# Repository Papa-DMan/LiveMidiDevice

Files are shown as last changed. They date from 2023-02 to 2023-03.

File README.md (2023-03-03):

# LiveMidiDevice
This repo merges my personal MIDI-Controller-DisplayDriver and MIDI-Controller repositories into this public one and also hosts the schematics and pcb designs for the project

The MIDI-Controller uses a tree and node structure. A FRDMK64F Dev board is the root of the tree and can handle up to two nodes right now. It utilizes the I2C bus with an extender chipset from TI to send data and power over an RJ45 8 connector cable down to the nodes that contain up to 8 buttons and 1 expression pedal and 1 led display controlled by and stm32 l412kb dev board.

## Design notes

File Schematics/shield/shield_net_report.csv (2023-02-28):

Net Code | Net Name | Pad Count | Via Count | Via Length | Track Length | Die Length | Net Length
001 | GND | 7 | 0 | 0.0000 mm | 80.9573 mm | 0.0000 mm | 80.9573 mm
002 | A0 | 3 | 0 | 0.0000 mm | 24.4699 mm | 0.0000 mm | 24.4699 mm
003 | A1 | 3 | 0 | 0.0000 mm | 15.3445 mm | 0.0000 mm | 15.3445 mm
004 | A4 | 3 | 0 | 0.0000 mm | 12.0241 mm | 0.0000 mm | 12.0241 mm
005 | A5 | 3 | 0 | 0.0000 mm | 17.7821 mm | 0.0000 mm | 17.7821 mm
006 | 5V | 15 | 0 | 0.0000 mm | 109.7009 mm | 0.0000 mm | 109.7009 mm
013 | VIN | 1 | 0 | 0.0000 mm | 0.0000 mm | 0.0000 mm | 0.0000 mm
014 | RST | 1 | 0 | 0.0000 mm | 0.0000 mm | 0.0000 mm | 0.0000 mm
015 | P3V3 | 1 | 0 | 0.0000 mm | 0.0000 mm | 0.0000 mm | 0.0000 mm
016 | Net-(U2-Pad5) | 4 | 0 | 0.0000 mm | 22.8535 mm | 0.0000 mm | 22.8535 mm
017 | Net-(U2-Pad2) | 4 | 0 | 0.0000 mm | 31.0575 mm | 0.0000 mm | 31.0575 mm
018 | Net-(U1-Pad5) | 4 | 0 | 0.0000 mm | 23.1029 mm | 0.0000 mm | 23.1029 mm
019 | Net-(U1-Pad2) | 4 | 0 | 0.0000 mm | 29.7947 mm | 0.0000 mm | 29.7947 mm
020 | D9 | 1 | 0 | 0.0000 mm | 0.0000 mm | 0.0000 mm | 0.0000 mm
021 | D8 | 1 | 0 | 0.0000 mm | 0.0000 mm | 0.0000 mm | 0.0000 mm
022 | D7B | 1 | 0 | 0.0000 mm | 0.0000 mm | 0.0000 mm | 0.0000 mm
023 | D7 | 2 | 0 | 0.0000 mm | 25.2753 mm | 0.0000 mm | 25.2753 mm
024 | D6B | 1 | 0 | 0.0000 mm | 0.0000 mm | 0.0000 mm | 0.0000 mm
025 | D6 | 2 | 0 | 0.0000 mm | 27.5409 mm | 0.0000 mm | 27.5409 mm
026 | D5B | 1 | 0 | 0.0000 mm | 0.0000 mm | 0.0000 mm | 0.0000 mm
027 | D5 | 1 | 0 | 0.0000 mm | 0.0000 mm | 0.0000 mm | 0.0000 mm
028 | D4B | 1 | 0 | 0.0000 mm | 0.0000 mm | 0.0000 mm | 0.0000 mm
029 | D4 | 1 | 0 | 0.0000 mm | 0.0000 mm | 0.0000 mm | 0.0000 mm
030 | D3B | 1 | 0 | 0.0000 mm | 0.0000 mm | 0.0000 mm | 0.0000 mm
031 | D3 | 1 | 0 | 0.0000 mm | 0.0000 mm | 0.0000 mm | 0.0000 mm
032 | D2B | 1 | 0 | 0.0000 mm | 0.0000 mm | 0.0000 mm | 0.0000 mm
033 | D2 | 1 | 0 | 0.0000 mm | 0.0000 mm | 0.0000 mm | 0.0000 mm
034 | D1B | 1 | 0 | 0.0000 mm | 0.0000 mm | 0.0000 mm | 0.0000 mm
035 | D15 | 1 | 0 | 0.0000 mm | 0.0000 mm | 0.0000 mm | 0.0000 mm
036 | D14 | 1 | 0 | 0.0000 mm | 0.0000 mm | 0.0000 mm | 0.0000 mm
037 | D13 | 1 | 0 | 0.0000 mm | 0.0000 mm | 0.0000 mm | 0.0000 mm
038 | D12 | 1 | 0 | 0.0000 mm | 0.0000 mm | 0.0000 mm | 0.0000 mm
039 | D11 | 1 | 0 | 0.0000 mm | 0.0000 mm | 0.0000 mm | 0.0000 mm
040 | D10 | 1 | 0 | 0.0000 mm | 0.0000 mm | 0.0000 mm | 0.0000 mm
041 | D1 | 1 | 0 | 0.0000 mm | 0.0000 mm | 0.0000 mm | 0.0000 mm
042 | D0B | 1 | 0 | 0.0000 mm | 0.0000 mm | 0.0000 mm | 0.0000 mm
043 | D0 | 1 | 0 | 0.0000 mm | 0.0000 mm | 0.0000 mm | 0.0000 mm
044 | AREF | 1 | 0 | 0.0000 mm | 0.0000 mm | 0.0000 mm | 0.0000 mm
045 | AD9 | 1 | 0 | 0.0000 mm | 0.0000 mm | 0.0000 mm | 0.0000 mm
046 | AD8 | 1 | 0 | 0.0000 mm | 0.0000 mm | 0.0000 mm | 0.0000 mm
047 | AD17 | 1 | 0 | 0.0000 mm | 0.0000 mm | 0.0000 mm | 0.0000 mm
048 | AD16 | 1 | 0 | 0.0000 mm | 0.0000 mm | 0.0000 mm | 0.0000 mm
049 | AD14 | 1 | 0 | 0.0000 mm | 0.0000 mm | 0.0000 mm | 0.0000 mm
050 | AD13 | 1 | 0 | 0.0000 mm | 0.0000 mm | 0.0000 mm | 0.0000 mm
051 | AD12 | 1 | 0 | 0.0000 mm | 0.0000 mm | 0.0000 mm | 0.0000 mm
052 | AD11 | 1 | 0 | 0.0000 mm | 0.0000 mm | 0.0000 mm | 0.0000 mm
053 | AD10 | 1 | 0 | 0.0000 mm | 0.0000 mm | 0.0000 mm | 0.0000 mm
054 | A9B | 1 | 0 | 0.0000 mm | 0.0000 mm | 0.0000 mm | 0.0000 mm
055 | A8B | 1 | 0 | 0.0000 mm | 0.0000 mm | 0.0000 mm | 0.0000 mm
056 | A7B | 1 | 0 | 0.0000 mm | 0.0000 mm | 0.0000 mm | 0.0000 mm
057 | A6B | 1 | 0 | 0.0000 mm | 0.0000 mm | 0.0000 mm | 0.0000 mm
058 | A5B | 1 | 0 | 0.0000 mm | 0.0000 mm | 0.0000 mm | 0.0000 mm
059 | A4B | 1 | 0 | 0.0000 mm | 0.0000 mm | 0.0000 mm | 0.0000 mm
060 | A3B | 1 | 0 | 0.0000 mm | 0.0000 mm | 0.0000 mm | 0.0000 mm
061 | A3 | 1 | 0 | 0.0000 mm | 0.0000 mm | 0.0000 mm | 0.0000 mm
062 | A2B | 1 | 0 | 0.0000 mm | 0.0000 mm | 0.0000 mm | 0.0000 mm
063 | A2 | 1 | 0 | 0.0000 mm | 0.0000 mm | 0.0000 mm | 0.0000 mm
064 | A1B | 1 | 0 | 0.0000 mm | 0.0000 mm | 0.0000 mm | 0.0000 mm
065 | A13B | 1 | 0 | 0.0000 mm | 0.0000 mm | 0.0000 mm | 0.0000 mm
066 | A12B | 1 | 0 | 0.0000 mm | 0.0000 mm | 0.0000 mm | 0.0000 mm
067 | A11B | 1 | 0 | 0.0000 mm | 0.0000 mm | 0.0000 mm | 0.0000 mm
068 | A10B | 1 | 0 | 0.0000 mm | 0.0000 mm | 0.0000 mm | 0.0000 mm
069 | A0B | 1 | 0 | 0.0000 mm | 0.0000 mm | 0.0000 mm | 0.0000 mm

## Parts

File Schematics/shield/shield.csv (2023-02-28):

Id | Designator | Package | Quantity | Designation | Supplier and ref
1 | R20,R18,R19,R17 | R_Axial_DIN0414_L11.9mm_D4.5mm_P5.08mm_Vertical | 4 | 91
2 | R9,R12,R11,R10 | R_Axial_DIN0207_L6.3mm_D2.5mm_P2.54mm_Vertical | 4 | 100k
3 | R25 | R_Axial_DIN0207_L6.3mm_D2.5mm_P2.54mm_Vertical | 1 | 5k1
4 | R24,R23,R22,R21 | R_1206_3216Metric_Pad1.30x1.75mm_HandSolder | 4 | 634
5 | R16,R15,R14,R13 | R_Axial_DIN0207_L6.3mm_D2.5mm_P2.54mm_Vertical | 4 | 10k
6 | R8,R7,R6,R5 | R_Axial_DIN0207_L6.3mm_D2.5mm_P2.54mm_Vertical | 4 | 5K1
7 | R4,R3,R2,R1 | R_Axial_DIN0207_L6.3mm_D2.5mm_P2.54mm_Vertical | 4 | 330
8 | U2,U1 | DIP-8_W7.62mm | 2 | P82B96
9 | C5,C6,C4,C3 | CP_Radial_Tantal_D5.5mm_P5.00mm | 4 | 10 uF
10 | U4,U3 | Texas_S-PVSON-N10 | 2 | OPA1622
11 | C18,C16,C19,C14,C21 | C_0402_1005Metric_Pad0.74x0.62mm_HandSolder | 5 | 0.01uF
12 | C8,C10,C7,C9 | C_1812_4532Metric_Pad1.57x3.40mm_HandSolder | 4 | COG 470pF
13 | U5 | SOIC-24 | 1 | CS5381K
14 | J2,J1 | RJ45_Amphenol_RJHSE538X | 2 | RJ45
15 | J4 | PinHeader_2x06_P2.54mm_Vertical | 1 | J4
16 | C1,C2 | C_Disc_D3.0mm_W1.6mm_P2.50mm | 2 | C
17 | C13 | C_1210_3225Metric_Pad1.33x2.70mm_HandSolder | 1 | 220uF
18 | C15,C17,C20 | C_0603_1608Metric_Pad1.08x0.95mm_HandSolder | 3 | 1uF
19 | J5 | PinHeader_2x10_P2.54mm_Vertical | 1 | J2
20 | J6 | PinHeader_2x08_P2.54mm_Vertical | 1 | J1
21 | C11,C12 | CP_Radial_D5.0mm_P2.50mm | 2 | 2700pF
22 | J3 | PinHeader_2x08_P2.54mm_Vertical | 1 | J3

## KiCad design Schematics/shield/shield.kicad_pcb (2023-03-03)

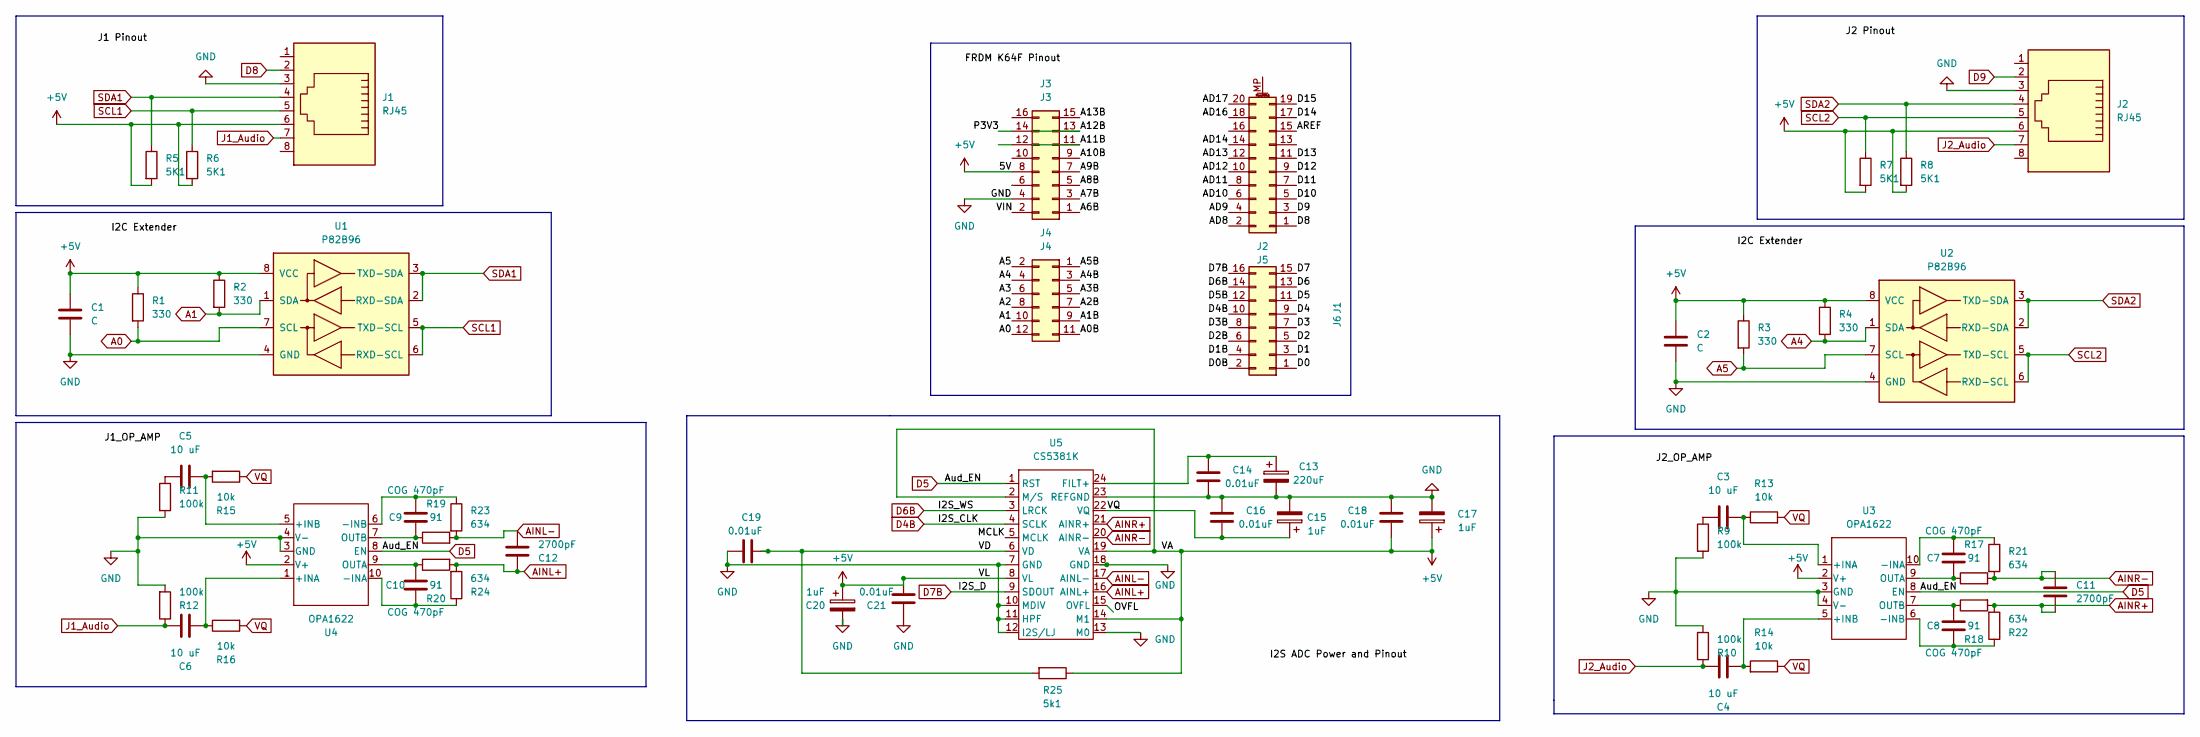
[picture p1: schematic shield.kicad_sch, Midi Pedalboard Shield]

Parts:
C1, C2: C; C_Disc_D3.0mm_W1.6mm_P2.50mm
C3, C4, C5, C6: 10 uF; CP_Radial_Tantal_D5.5mm_P5.00mm
C7, C8, C9, C10: COG 470pF; C_1812_4532Metric_Pad1.57x3.40mm_HandSolder
C11, C12: 2700pF; CP_Radial_D5.0mm_P2.50mm
C13: 220uF; C_1210_3225Metric_Pad1.33x2.70mm_HandSolder
C14, C16, C18, C19, C21: 0.01uF; C_0402_1005Metric_Pad0.74x0.62mm_HandSolder
C15, C17, C20: 1uF; C_0603_1608Metric_Pad1.08x0.95mm_HandSolder
J1, J2: RJ45; RJ45_Amphenol_RJHSE538X
J3: J3; PinHeader_2x08_P2.54mm_Vertical
J4: J4; PinHeader_2x06_P2.54mm_Vertical
J5: J2; PinHeader_2x10_P2.54mm_Vertical
J6: J1; PinHeader_2x08_P2.54mm_Vertical
R1, R2, R3, R4: 330; R_Axial_DIN0207_L6.3mm_D2.5mm_P2.54mm_Vertical
R5, R6, R7, R8: 5K1; R_Axial_DIN0207_L6.3mm_D2.5mm_P2.54mm_Vertical
R9, R10, R11, R12: 100k; R_Axial_DIN0207_L6.3mm_D2.5mm_P2.54mm_Vertical
R13, R14, R15, R16: 10k; R_Axial_DIN0207_L6.3mm_D2.5mm_P2.54mm_Vertical
R17, R18, R19, R20: 91; R_Axial_DIN0414_L11.9mm_D4.5mm_P5.08mm_Vertical
R21, R22, R23, R24: 634; R_1206_3216Metric_Pad1.30x1.75mm_HandSolder
R25: 5k1; R_Axial_DIN0207_L6.3mm_D2.5mm_P2.54mm_Vertical
U1, U2: P82B96; DIP-8_W7.62mm
U3, U4: OPA1622; Texas_S-PVSON-N10
U5: CS5381K; SOIC-24

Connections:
+5V: C1.1, C2.1, C17.1, C18.2, C20.1, C21.2, J1.6, J2.6, J3.8, R1.1, R2.1, R3.1, R4.1, R5.2, R6.2, R7.2, R8.2, R25.1, U1.8 (VCC), U2.8 (VCC), U3.2 (V+), U4.2 (V+), U5.2 (M/S), U5.8 (VL), U5.14 (M1), U5.19 (VA)
/A0B: J4.11
/A1B: J4.9
/A2: J4.8
/A2B: J4.7
/A3: J4.6
/A3B: J4.5
/A4B: J4.3
/A5B: J4.1
/A6B: J3.1
/A7B: J3.3
/A8B: J3.5
/A9B: J3.7
/A10B: J3.9
/A11B: J3.11
/A12B: J3.13
/A13B: J3.15
/AD8: J5.2
/AD9: J5.4
/AD10: J5.6
/AD11: J5.8
/AD12: J5.10
/AD13: J5.12
/AD14: J5.14
/AD16: J5.18
/AD17: J5.20
/AREF: J5.15
/D0: J6.1
/D0B: J6.2
/D1: J6.3
/D1B: J6.4
/D2: J6.5
/D2B: J6.6
/D3: J6.7
/D3B: J6.8
/D4: J6.9
/D5B: J6.12
/D6: J6.13
/D7: J6.15
/D10: J5.5
/D11: J5.7
/D12: J5.9
/D13: J5.11
/D14: J5.17
/D15: J5.19
/MCLK: U5.5 (MCLK)
/OVFL: U5.15 (OVFL)
/P3V3: J3.14
/VD: C19.1, R25.2, U5.6 (VD)
A0: J4.12, R1.2, U1.7 (SCL)
A1: J4.10, R2.2, U1.1 (SDA)
A4: J4.4, R4.2, U2.1 (SDA)
A5: J4.2, R3.2, U2.7 (SCL)
AINL+: C12.1, R20.2, R24.2, U5.16 (AINL+)
AINL-: C12.2, R19.2, R23.2, U5.17 (AINL-)
AINR+: C11.2, R18.2, R22.2, U5.21 (AINR+)
AINR-: C11.1, R17.2, R21.2, U5.20 (AINR-)
D4B: J6.10, U5.4 (SCLK)
D5: J6.11, U3.8 (EN), U4.8 (EN), U5.1 (RST)
D6B: J6.14, U5.3 (LRCK)
D7B: J6.16, U5.9 (SDOUT)
D8: J1.2, J5.1
D9: J2.2, J5.3
GND: C1.2, C2.2, C13.2, C14.2, C15.2, C16.1, C17.2, C18.1, C19.2, C20.2, C21.1, J1.3, J2.3, J3.4, R9.2, R10.2, R11.2, R12.2, U1.4 (GND), U2.4 (GND), U3.3 (GND), U3.4 (V-), U4.3 (GND), U4.4 (V-), U5.7 (GND), U5.10 (MDIV), U5.11 (HPF), U5.12 (I2S/LJ), U5.13 (M0), U5.18 (GND), U5.23 (REFGND)
J1_Audio: C6.1, J1.7, R12.1
J2_Audio: C4.1, J2.7, R10.1
unnamed: C3.1, R9.1
unnamed: C3.2, R13.1, U3.1 (+INA)
unnamed: C4.2, R14.2, U3.5 (+INB)
unnamed: C5.1, R11.1
unnamed: C5.2, R15.2, U4.5 (+INB)
unnamed: C6.2, R16.1, U4.1 (+INA)
unnamed: C7.1, R17.1, U3.9 (OUTA)
unnamed: C7.2, R21.1, U3.10 (-INA)
unnamed: C8.1, R18.1, U3.7 (OUTB)
unnamed: C8.2, R22.1, U3.6 (-INB)
unnamed: C9.1, R19.1, U4.7 (OUTB)
unnamed: C9.2, R23.1, U4.6 (-INB)
unnamed: C10.1, R20.1, U4.9 (OUTA)
unnamed: C10.2, R24.1, U4.10 (-INA)
unnamed: C13.1, C14.1, U5.24 (FILT+)
SCL1: J1.5, R6.1, U1.5 (TXD-SCL), U1.6 (RXD-SCL)
SCL2: J2.5, R7.1, U2.5 (TXD-SCL), U2.6 (RXD-SCL)
SDA1: J1.4, R5.1, U1.2 (RXD-SDA), U1.3 (TXD-SDA)
SDA2: J2.4, R8.1, U2.2 (RXD-SDA), U2.3 (TXD-SDA)
VQ: C15.1, C16.2, R13.2, R14.1, R15.1, R16.2, U5.22 (VQ)

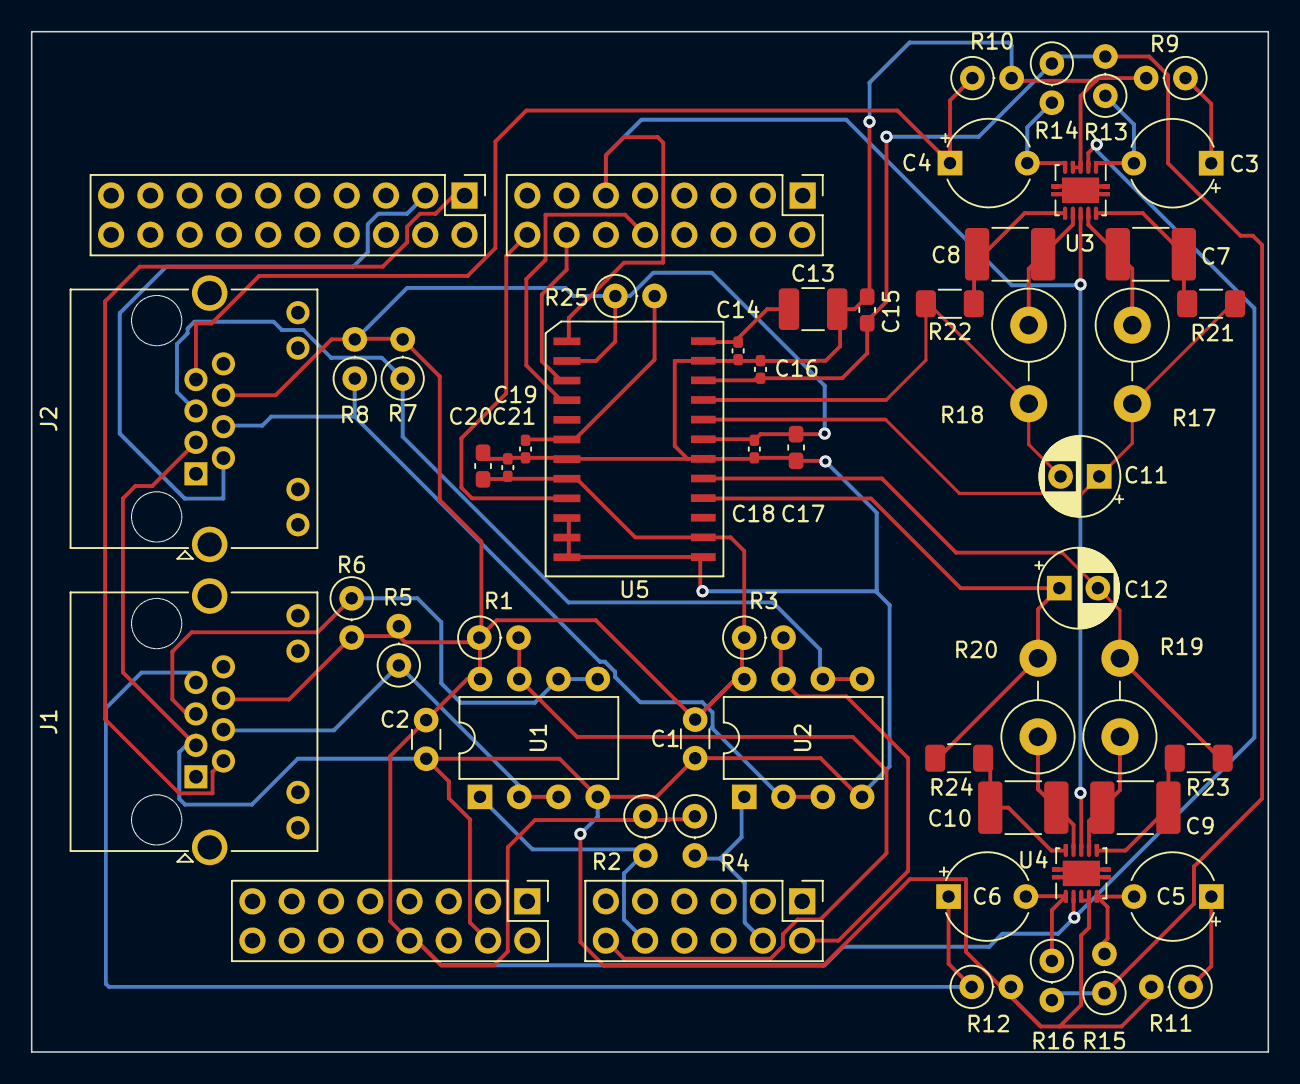
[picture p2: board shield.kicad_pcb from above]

Board: 2 copper layers, 80.0 x 66.0 mm, 57 parts (0 on the bottom side), 39 nets.

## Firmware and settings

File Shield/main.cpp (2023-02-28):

#include "mbed.h"
#include "fsl_sai.h"
#include "USBAudio.h"
#include "USBMIDI.h"
#include "MCP23017.h"
#include "MCP3021.h"

//I2C j1(A1, A0);
//I2C j2(A4, A5);


USBAudio usba(true, 48000, 1, 192000, 2);
USBMIDI usbm;

DigitalOut led(LED_BLUE);


const _sai_config conf = {kSAI_BusI2S, kSAI_ModeSync, false, kSAI_MclkSourceSysclk, kSAI_BclkSourceOtherSai0, kSAI_Slave};




I2S_Type* base = (I2S_Type*)0x4002F000u;

uint8_t bufl[4];
uint8_t bufr[4];

const int lchannels[6] = {20,21,22,23,24,11};
const int rchannels[6] = {30,31,32,33,34,12};

DigitalIn j2_enable(D9);
DigitalIn j1_enable(D8);
DigitalOut audio_enable(D5);

Thread audio;
Thread midil;
Thread midir;



void audio_thread()
{
    SAI_RxInit(base,&conf);
    ThisThread::sleep_for(500ms);
    audio_enable.write(true);

    while (true) {
        uint32_t ldata = SAI_ReadData(base, 0);
        bufl[0] = ((ldata >> 24) & 0xFF);
        bufl[1] = ((ldata >> 16) & 0xFF);
        bufl[2] = ((ldata >> 8) & 0xFF);
        bufl[3] = (ldata & 0xFF);
        usba.write(bufl, 4);

        uint32_t rdata = SAI_ReadData(base, 0);
        bufr[0] = ((rdata >> 24) & 0xFF);
        bufr[1] = ((rdata >> 16) & 0xFF);
        bufr[2] = ((rdata >> 8) & 0xFF);
        bufr[3] = (rdata & 0xFF);
        usba.write(bufr, 4);

    }
}

/*
void midi_thread(I2C& i2c, DigitalIn *enable, const int *channels) {

    while (!enable->read()) {
        //nop
    }
    MCP23017 gpio(i2c, 0x40);
    MCP3021 adc(i2c, 5.0);
    int prev_mask = 0x00;
    double prev_pedal = 0.0;
    
    while (true) {
        char cur_mask = gpio.readRegister8(0x12);
        if ((cur_mask & 0x01) && !(prev_mask & 0x01)) {
            usbm.write(MIDIMessage::ControlChange(channels[0], 127));
        }
        if ((cur_mask & 0x02) && !(prev_mask & 0x02)) {
            usbm.write(MIDIMessage::ControlChange(channels[1], 127));
        }
        if ((cur_mask & 0x04) && !(prev_mask & 0x04)) {
            usbm.write(MIDIMessage::ControlChange(channels[2], 127));
        }
        if ((cur_mask & 0x08) && !(prev_mask & 0x08)) {
            usbm.write(MIDIMessage::ControlChange(channels[3], 127));
        }
        if ((cur_mask & 0x10) && !(prev_mask & 0x10)) {
            usbm.write(MIDIMessage::ControlChange(channels[4], 127));
        }
        double a = adc.read();
        if (a != prev_pedal) {
            usbm.write(MIDIMessage::ControlChange(channels[5], a));
        }
        prev_mask = cur_mask;
        prev_pedal = a;
    }
}

void midil_thread() {
    midi_thread(j1, &j1_enable, lchannels);
}
void midir_thread() {
    midi_thread(j2, &j2_enable, rchannels);
}
*/

int main() {
    audio.start(audio_thread);
//    midil.start(midil_thread);
//    midir.start(midir_thread);
    while(true) {
        //noop
        led.write(0);
        ThisThread::sleep_for(500ms);
        led.write(1);
        ThisThread::sleep_for(500ms);
    }
}

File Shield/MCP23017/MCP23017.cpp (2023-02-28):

/*  MCP23017 library for Arduino
    Copyright (C) 2009 David Pye    <davidmpye@gmail.com
    Modified for use on the MBED ARM platform

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
    You should have received a copy of the GNU General Public License
    along with this program.  If not, see <http://www.gnu.org/licenses/>.
*/

#include "MCP23017.h"
#include "mbed.h"

union {
    uint8_t  value8[2];
    uint16_t value16;
} tmp_data;

/*-----------------------------------------------------------------------------
 *
 */
MCP23017::MCP23017(I2C & i2c, int i2cAddress)  : _i2c(i2c) {
    MCP23017_i2cAddress = i2cAddress;
    //reset();                                  // initialise chip to power-on condition
}

/*-----------------------------------------------------------------------------
 * reset
 * Set configuration (IOCON) and direction(IODIR) registers to initial state
 */
void MCP23017::reset() {
//
// First make sure that the device is in BANK=0 mode
//
    writeRegister(0x05, (unsigned char)0x00);
//
// set direction registers to inputs
//
    writeRegister(IODIR, (unsigned short)0xFFFF);
//
// set all other registers to zero (last of 10 registers is OLAT)
//
    for (int reg_addr = 2 ; reg_addr <= OLAT ; reg_addr+=2) {
        writeRegister(reg_addr, (unsigned short)0x0000);
    }
//
// Set the shadow registers to power-on state
//
    shadow_IODIR = 0xFFFF;
    shadow_GPIO  = 0;
    shadow_GPPU  = 0;
    shadow_IPOL  = 0;
}


/*-----------------------------------------------------------------------------
 * write_bit
 * Write a 1/0 to a single bit of the 16-bit port
 */
void MCP23017::write_bit(int value, int bit_number) {
    if (value == 0) {
        shadow_GPIO &= ~(1 << bit_number);
    } else {
        shadow_GPIO |= 1 << bit_number;
    }
    writeRegister(GPIO, (unsigned short)shadow_GPIO);
}

/*-----------------------------------------------------------------------------
 * Write a combination of bits to the 16-bit port
 */
void MCP23017::write_mask(unsigned short data, unsigned short mask) {
    shadow_GPIO = (shadow_GPIO & ~mask) | data;
    writeRegister(GPIO, (unsigned short)shadow_GPIO);
}

/*void MCP23017::write_mask(unsigned char data, unsigned char mask) {
    shadow_GPIO = (shadow_GPIO & ~mask) | data;
    writeRegister(GPIO, (unsigned short)shadow_GPIO);
}
*/
/*-----------------------------------------------------------------------------
 * read_bit
 * Read a single bit from the 16-bit port
 */
int  MCP23017::read_bit(int bit_number) {
    shadow_GPIO = readRegister(GPIO);
    return  ((shadow_GPIO >> bit_number) & 0x0001);
}

/*-----------------------------------------------------------------------------
 * read_mask
 */
int  MCP23017::read_mask(unsigned short mask) {
    shadow_GPIO = readRegister(GPIO);
    return (shadow_GPIO & mask);
}

/*-----------------------------------------------------------------------------
 * Config
 * set direction and pull-up registers
 */
void MCP23017::config(unsigned short dir_config, unsigned short pullup_config,  unsigned short polarity_config) {
    shadow_IODIR = dir_config;
    writeRegister(IODIR, (unsigned short)shadow_IODIR);
    shadow_GPPU = pullup_config;
    writeRegister(GPPU, (unsigned short)shadow_GPPU);
    shadow_IPOL = polarity_config;
    writeRegister(IPOL, (unsigned short)shadow_IPOL);
}

/*-----------------------------------------------------------------------------
 * writeRegister
 * write a byte
 */
void MCP23017::writeRegister(int regAddress, unsigned char data) {
    char  buffer[2];

    buffer[0] = regAddress;
    buffer[1] = data;
    _i2c.write(MCP23017_i2cAddress, buffer, 2);
}

/*----------------------------------------------------------------------------
 * write Register
 * write two bytes
 */ 
void MCP23017::writeRegister(int regAddress, unsigned short data) {
    char  buffer[3];

    buffer[0] = regAddress;
    tmp_data.value16 = data;
    buffer[1] = tmp_data.value8[0];
    buffer[2] = tmp_data.value8[1];

    _i2c.write(MCP23017_i2cAddress, buffer, 3);
}

/*-----------------------------------------------------------------------------
 * readRegister
 */
int MCP23017::readRegister(int regAddress) {
    char buffer[2];

    buffer[0] = regAddress;
    _i2c.write(MCP23017_i2cAddress, buffer, 1);
    _i2c.read(MCP23017_i2cAddress, buffer, 2);

    return ((int)(buffer[0] + (buffer[1]<<8)));
}

char MCP23017::readRegister8(int regAddress) {
    char buffer[2];

    buffer[0] = regAddress;
    _i2c.write(MCP23017_i2cAddress, buffer, 1, true);
    _i2c.read(MCP23017_i2cAddress, buffer, 1);

    return(buffer[0]);
}

/*-----------------------------------------------------------------------------
 * pinMode
 */
void MCP23017::pinMode(int pin, int mode) {
    if (mode == DIR_INPUT) {
        shadow_IODIR |= 1 << pin;
    } else {
        shadow_IODIR &= ~(1 << pin);
    }
    writeRegister(IODIR, (unsigned short)shadow_IODIR);
}

/*-----------------------------------------------------------------------------
 * digitalRead
 */
int MCP23017::digitalRead(int pin) {
    shadow_GPIO = readRegister(GPIO);
    if ( shadow_GPIO & (1 << pin)) {
        return 1;
    } else {
        return 0;
    }
}

/*-----------------------------------------------------------------------------
 * digitalWrite
 */
void MCP23017::digitalWrite(int pin, int val) {
    //If this pin is an INPUT pin, a write here will
    //enable the internal pullup
    //otherwise, it will set the OUTPUT voltage
    //as appropriate.
    bool isOutput = !(shadow_IODIR & 1<<pin);

    if (isOutput) {
        //This is an output pin so just write the value
        if (val) shadow_GPIO |= 1 << pin;
        else shadow_GPIO &= ~(1 << pin);
        writeRegister(GPIO, (unsigned short)shadow_GPIO);
    } else {
        //This is an input pin, so we need to enable the pullup
        if (val) {
            shadow_GPPU |= 1 << pin;
        } else {
            shadow_GPPU &= ~(1 << pin);
        }
        writeRegister(GPPU, (unsigned short)shadow_GPPU);
    }
}

/*-----------------------------------------------------------------------------
 * digitalWordRead
 */
unsigned short MCP23017::digitalWordRead() {
    shadow_GPIO = readRegister(GPIO);
    return shadow_GPIO;
}

/*-----------------------------------------------------------------------------
 * digitalWordWrite
 */
void MCP23017::digitalWordWrite(unsigned short w) {
    shadow_GPIO = w;
    writeRegister(GPIO, (unsigned short)shadow_GPIO);
}

/*-----------------------------------------------------------------------------
 * inputPolarityMask
 */
void MCP23017::inputPolarityMask(unsigned short mask) {
    writeRegister(IPOL, mask);
}

/*-----------------------------------------------------------------------------
 * inputoutputMask
 */
void MCP23017::inputOutputMask(unsigned short mask) {
    shadow_IODIR = mask;
    writeRegister(IODIR, (unsigned short)shadow_IODIR);
}
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

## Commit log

2023-02-28 added schematics
    [pedalboard.kicad_pcb, pedalboard.kicad_sch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]
2023-03-03 update schematic
2023-03-03 Fixed Schematic. The FRDM K64F pin positions were one step too wide so narrowed and updated tracks. The pads for the I2S ADC IC were too narrow so wided to the maximum Spec. Updated Silkscreen to be 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
    [shield-B_Cu.gbr, shield-B_Mask.gbr, shield-B_Paste.gbr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]
2023-03-08 Update Gerber Zip
2023-03-15 generated .cad and stencil files for fab
    [shield-B_Cu.gbr, shield-B_Mask.gbr, shield-B_Paste.gbr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]

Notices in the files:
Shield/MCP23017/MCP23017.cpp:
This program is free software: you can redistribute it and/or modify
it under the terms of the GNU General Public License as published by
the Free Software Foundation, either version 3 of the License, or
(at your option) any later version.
